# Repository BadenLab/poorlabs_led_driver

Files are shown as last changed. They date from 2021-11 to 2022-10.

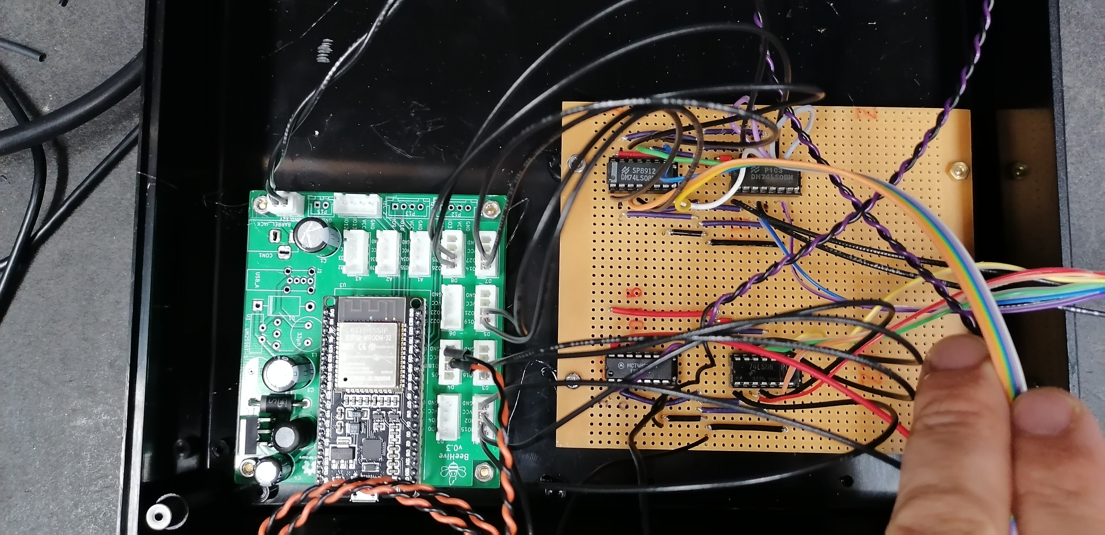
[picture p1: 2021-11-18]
media/IMG_20211118_184615.jpg

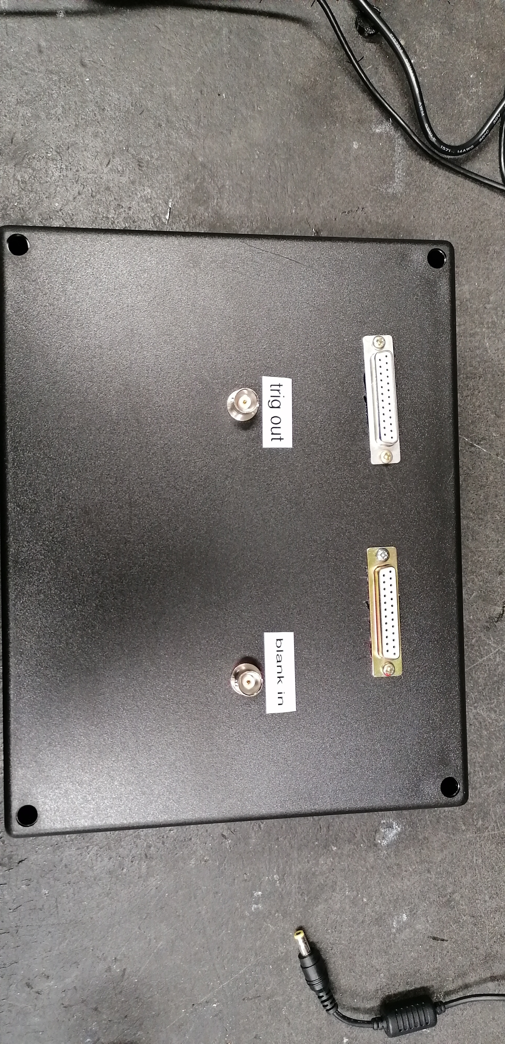
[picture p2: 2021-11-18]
media/IMG_20211118_184739.jpg

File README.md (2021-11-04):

# Poorlabs stimulus generator
A custom driver for Chrolis LED system from ThorLabs

This repository contains all the documentation needed to build a custom driver for a [Chrolis LED system from Thorlabs](https://www.thorlabs.com/newgrouppage9.cfm?objectgroup_id=13597).

Features:
- Synchronisation with 2 photon microscope blanking signal (or any other synchronisation TTL pulse)
  - Synchronisation done via hardware, dispensing the need to include complicated logic on the microcontroller
- Based on ESP32 (uses [BeeHive](https://github.com/BeeHive-org/BeeHive) main breakout board)
- Set of stimuli provided. Based on [Led Zappelin's code](https://github.com/BadenLab/LED-Zappelin)

Skills required:
- Coding (Arduino IDE / Micropython)
- Soldering
- Using a drill, screwdriver

Links/tutorials used:
- [getting started with ESP 32 and micropython](https://docs.micropython.org/en/latest/esp32/tutorial/intro.html)
- [controlling an ESP with micropython via a Jupyter notebook](https://towardsdatascience.com/micropython-on-esp-using-jupyter-6f366ff5ed9) 
- datasheets:
  - [Chips performing logical AND on the signals to control each LED and the blanking signal](https://www.mouser.co.uk/datasheet/2/308/74LS08-1190273.pdf)
  - [Chip inverting the blanking signal (logical NOT)](https://www.mouser.co.uk/datasheet/2/308/1/MC74HC14A_D-2315678.pdf)

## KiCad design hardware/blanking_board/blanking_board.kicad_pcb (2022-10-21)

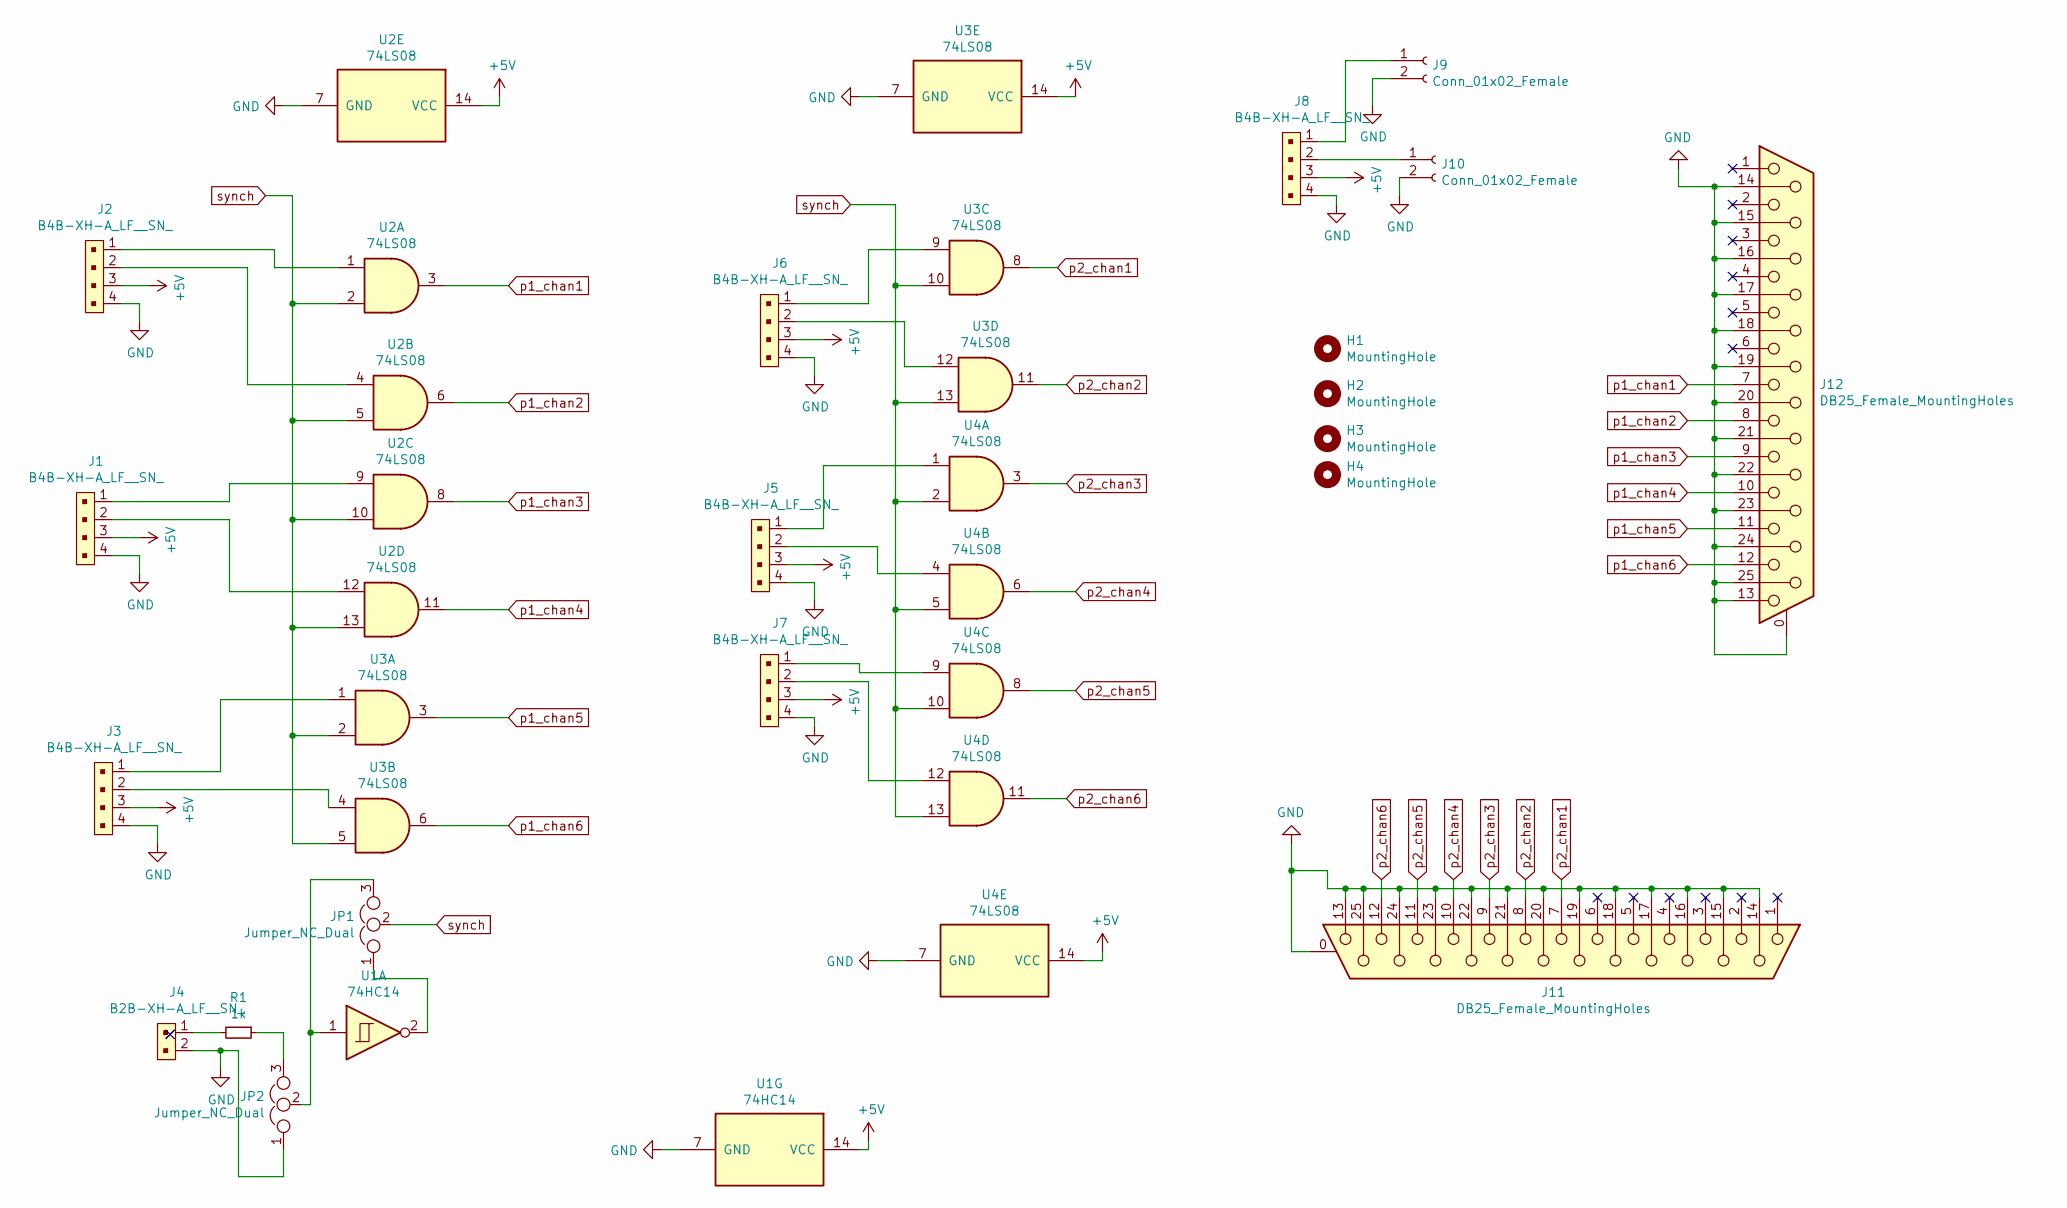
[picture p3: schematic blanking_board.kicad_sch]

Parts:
H1, H2, H3, H4: MountingHole; MountingHole_3.2mm_M3_ISO7380
J1, J2, J3, J5, J6, J7, J8: B4B-XH-A_LF__SN_; JST_XH_B4B-XH-A_1x04_P2.50mm_Vertical; MPN B4B-XH-A(LF)(SN); Digi-Key_PN 455-2249-ND
J4: B2B-XH-A_LF__SN_; JST_XH_B2B-XH-A_1x02_P2.50mm_Vertical; MPN B2B-XH-A(LF)(SN); Digi-Key_PN 455-2247-ND
J9, J10: Conn_01x02_Female; JST_XH_B2B-XH-A_1x02_P2.50mm_Vertical
J11, J12: DB25_Female_MountingHoles; PinHeader_2x13_P2.54mm_Vertical
JP1, JP2: Jumper_NC_Dual; PinHeader_1x03_P2.54mm_Vertical
R1: 1k; R_Axial_DIN0411_L9.9mm_D3.6mm_P15.24mm_Horizontal
U1: 74HC14; DIP-14_W7.62mm_LongPads
U2, U3, U4: 74LS08; DIP-14_W7.62mm_LongPads

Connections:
+5V: J1.3, J2.3, J3.3, J5.3, J6.3, J7.3, J8.3, U1.14 (VCC), U2.14 (VCC), U3.14 (VCC), U4.14 (VCC)
GND: J1.4, J2.4, J3.4, J4.2, J5.4, J6.4, J7.4, J8.4, J9.2, J10.2, J11.0 (PAD), J11.13, J11.14, J11.15, J11.16, J11.17, J11.18, J11.19, J11.20, J11.21, J11.22, J11.23, J11.24, J11.25, J12.0 (PAD), J12.13, J12.14, J12.15, J12.16, J12.17, J12.18, J12.19, J12.20, J12.21, J12.22, J12.23, J12.24, J12.25, JP2.1, U1.7 (GND), U2.7 (GND), U3.7 (GND), U4.7 (GND)
unnamed: J1.1, U2.9
unnamed: J1.2, U2.12
unnamed: J2.1, U2.1
unnamed: J2.2, U2.4
unnamed: J3.1, U3.1
unnamed: J3.2, U3.4
unnamed: J4.1, R1.2
unnamed: J5.1, U4.1
unnamed: J5.2, U4.4
unnamed: J6.1, U3.9
unnamed: J6.2, U3.12
unnamed: J7.1, U4.9
unnamed: J7.2, U4.12
unnamed: J8.1, J9.1
unnamed: J8.2, J10.1
unnamed: JP1.1, U1.2
unnamed: JP1.3, JP2.2, U1.1
unnamed: JP2.3, R1.1
p1_chan1: J12.7, U2.3
p1_chan2: J12.8, U2.6
p1_chan3: J12.9, U2.8
p1_chan4: J12.10, U2.11
p1_chan5: J12.11, U3.3
p1_chan6: J12.12, U3.6
p2_chan1: J11.7, U3.8
p2_chan2: J11.8, U3.11
p2_chan3: J11.9, U4.3
p2_chan4: J11.10, U4.6
p2_chan5: J11.11, U4.8
p2_chan6: J11.12, U4.11
synch: JP1.2, U2.2, U2.5, U2.10, U2.13, U3.2, U3.5, U3.10, U3.13, U4.2, U4.5, U4.10, U4.13

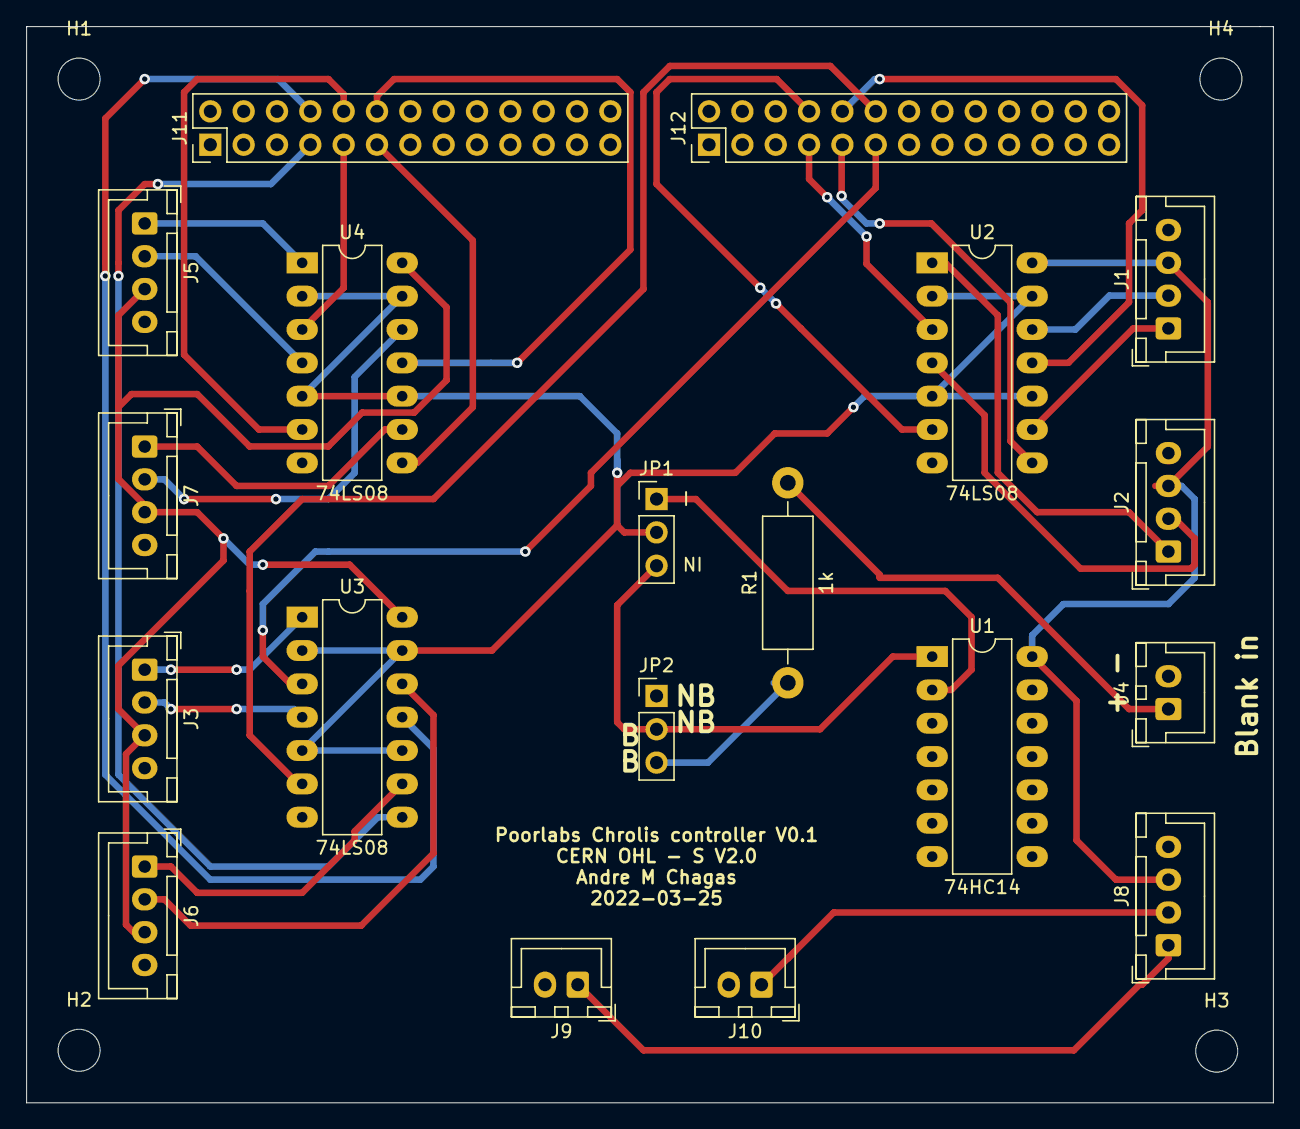
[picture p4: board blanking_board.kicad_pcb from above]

Board: 2 copper layers, 95.0 x 82.0 mm, 23 parts (0 on the bottom side), 33 nets.

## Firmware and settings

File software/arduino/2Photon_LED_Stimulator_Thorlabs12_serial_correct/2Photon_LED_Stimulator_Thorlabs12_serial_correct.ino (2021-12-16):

/*
 * Adapting this code to only ESP32:
 * Change the LEDX values (in the very beginning of the code), to values that correspond to pin numbers on the Beehive 0.3 board
 * change the "tlc.setPWM(ledX,0);" calls to "ledcWrite(ledX, value)"
 * remove or comment out "tlc.write()"
 * 
 * 
 */


/* 
 
        LED Zappelin' is an open hardware LED stimulator that can individually                                                                                                                                                                                                                                                                                                                                      
control up to 24 LEDs.

This Arduino file is designed to be uploaded on an Adafruit_HUZZAH ESP32 Feather or an Arduino Nano
Source : https://github.com/BadenLab/LED-Zappelin
The script relies on an incoming blanking signal, generated by a TTL, which updates the LEDs.
The stimulus speed has to be adjusted to the scan logic (scanning mirrors speed that corresponds to 
the blanking signal generated by the TTL): 1kHz/1ms, 500Hz/2ms, etc.
A trigger signal is generated at the begining of the stimulus and then every 1.0 seconds.

Library "Adafruit TLC5947" needs to be installed.
 
The default script is parametered for 4 LEDs (connected to pin 0 to 3), and their respective proxy LEDs 
(connected to pin 4 to 7)


This project is Open Source licensed, released under CERN OHL v1.2

by  M.J.Y. Zimmermann, 2019.02.05
Baden Lab, CRPC, School of Life Sciences, University of Sussex, United Kingdom
*/


//libraries
#include <SerialCommand.h>


/* ------------------------------------------------------------------------------------
                           Stimulus parameters
-------------------------------------------------------------------------------------*/                                                                                             

int           nLoops           = 500;     //  Number of repeats of the arrays (i.e. Loops)
const int     nArrayEntries    = 3;       //  Number of entries in the arrays, including preadaption at position 0
const int     Scan_Logic       = 2;       //  Scanning logic (1 for 1ms scans, 2 for 2ms scans, etc.)



// // // // // // // // // // // // // // // // // // // // // // // // // // //
// // // // // // // // // STIMULUS SEQUENCE START // // // // // // // // // //
// // // // // // // // // // // // // // // // // // // // // // // // // // // 

// The array_LED# values are expressed in percentage and should only be expressed from 0-100
const int8_t array_LED1[] PROGMEM = {
0,100,0
};
const int8_t array_LED2[] PROGMEM = {    
0,0,0
};
const int8_t array_LED3[] PROGMEM = {    
0,0,0
};
const int8_t array_LED4[] PROGMEM = {
0,0,0
};

const int8_t array_LED5[] PROGMEM = {
0,0,0
};
const int8_t array_LED6[] PROGMEM = {    
0,0,0
};
const int8_t array_LED7[] PROGMEM = {    
0,0,0
};
const int8_t array_LED8[] PROGMEM = {
0,0,0
};
const int8_t array_LED9[] PROGMEM = {
0,0,0
};
const int8_t array_LED10[] PROGMEM = {    
0,0,0
};
const int8_t array_LED11[] PROGMEM = {    
0,0,0
};
const int8_t array_LED12[] PROGMEM = {
0,0,0
};


// The array_Time values are expressed in milliseconds
const int16_t array_Time[] PROGMEM = {      
10,1000,1000
};

// // // // // // // // // // // // // // // // // // // // // // // // // // //
// // // // // // //  STIMULUS SEQUENCE END  // // // // // // // // // // // //
// // // // // // // // // // // // // // // // // // // // // // // // // // //


/* ------------------------------------------------------------------------------------
                           Microcontroller Board Selection
-------------------------------------------------------------------------------------*/

      //#define Arduino_Nano
      //#define Adafruit_ESP32

      
/* ------------------------------------------------------------------------------------
                    Internal Definitions (Change at your own risk)
-------------------------------------------------------------------------------------*/
// setting PWM properties
const int freq = 5000;
const int resolution = 12;

// defining LEDs arduino channels
const int led1Channel = 0;
const int led2Channel = 1;
const int led3Channel = 2;
const int led4Channel = 3;

const int led5Channel = 4;
const int led6Channel = 5;
const int led7Channel = 6;
const int led8Channel = 7;
const int led9Channel = 8;
const int led10Channel = 9;
const int led11Channel = 10;
const int led12Channel = 11;



#include "LED_Values.h"                     // Include LED Values defined in the second tab
/*
#include <SPI.h>                            // Include the arduino serial port interface library
#include "Adafruit_TLC5947.h"               // Include the Adafruit TLC5947 libvrary. For better result one may change the number of channel defined in the Adafruit_TLC5947.cpp library


#ifdef Arduino_Nano
    #define   data            4             // SPI connection, DIN connected to pin D4
    #define   clock           5             // SPI connection, CLK connected to pin D5
    #define   latch           6             // SPI connection, LAT connected to pin D6
    //#define   oe              2           // Optional feature to prevent LED to light up when powering up the TLC board connected to pin D2
    const int      pSyncOut      =   A0;    // Trigger channel must be connected to pin A0
    const int      pBlank        =   3;     // Blanking signal channel must be connected to pin D3
#endif

#ifdef Adafruit_ESP32
    #define   data           18             // SPI connection, DIN connected to pin MOSI/18
    #define   clock           5             // SPI connection, CLK connected to pin SCK/5
    #define   latch          21             // SPI connection, LAT connected to pin 21
    //#define   oe            25            // Optional feature to prevent LED to light up when powering up the TLC board connected to pin A1/DAC1
    const int      pSyncOut      =   26;    // Trigger channel must be connected to pin A0/DAC2
    const int      pBlank        =   36;    // Blanking signal channel must be connected to pin A4/36
#endif

//    Adafruit_TLC5947 tlc = Adafruit_TLC5947(1, clock, data, latch);

*/
    

/* Global variables */  

//char           sCmd;                        // Serial monitor 
SerialCommand sCmd;     // The demo SerialCommand object
int            i;                           // iteration loop factor
word           BaudRate      = 115200;      // Baud Rate
// Label LEDs with GPIO pins
int            led1Pin       = 16;           // Define 1st Channel (Beehive)       
int            led2          = 17;           // Define 2nd Channel
int            led3          = 5;            // Define 3rd Channel
int            led4          = 18;           // Define 4th Channel

int            led5          = 19;           // Define 5th Channel        
int            led6          = 21;           // Define 6th Channel
int            led7          = 22;           // Define 7th Channel 
int            led8          = 23;           // Define 8th Channel 
int            led9          = 14;           // Define 9th Channel (Beehive)
int            led10         = 27;           // Define 10th Channel (Beehive)
int            led11         = 26;          // Define 11th Channel (Beehive)
int            led12         = 25;          // Define 12th Channel (Beehive)


/* Global LED variables */
volatile word   stled1;                     // First LED value   
volatile word   stled2;                     // Second LED value
volatile word   stled3;                     // Third LED value
volatile word   stled4;                     // Fourth LED value

volatile word   stled5;                     // Fifth LED value   
volatile word   stled6;                     // Sixth LED value
volatile word   stled7;                     // Seventh LED value
volatile word   stled8;                     // Eighth LED value
volatile word   stled9;                     // Ninth LED value   
volatile word   stled10;                     // Tenth LED value
volatile word   stled11;                     // Eleventh LED value
volatile word   stled12;                     // Twelfth LED value

word            array1[nArrayEntries];      // First LED Array
word            array2[nArrayEntries];      // Second LED Array
word            array3[nArrayEntries];      // Third LED Array
word            array4[nArrayEntries];      // Fourth LED Array

word            array5[nArrayEntries];      // Fifth LED Array
word            array6[nArrayEntries];      // Sixth LED Array
word            array7[nArrayEntries];      // Seventh LED Array
word            array8[nArrayEntries];      // Eighth LED Array
word            array9[nArrayEntries];      // Ninth LED Array
word            array10[nArrayEntries];      // Tenth LED Array
word            array11[nArrayEntries];      // Eleventh LED Array
word            array12[nArrayEntries];      // Twelfth LED Array


/* Timing variables */
volatile word  pulse;                                             // Pulse number
word           Time[nArrayEntries];                               // Time Array
float          x_Logic            =   1.0/Scan_Logic;             // Factor applied to the timing according to the scanning logic

/* Trigger variables */
int     Trigger_Duration            =   25;                       // Length of the Trigger signal in ms
int     TriggerCounter_Duration     =   1000;                     // Lenght of the Trigger loop in ms
word    Trigger_dur        =   Trigger_Duration * x_Logic;        // Trigger signal duration adjusted
word    TriggerCounter_dur =   TriggerCounter_Duration * x_Logic; // Trigger loop duration adjusted  
    
/* Reset Parameters */
volatile word  iLoop                = 0;       // Actual loop number = iLoop + 1
volatile word  PulseCount           = 0;       // Count the number of pulses delivered by the blanking signal
volatile int   PulseCount_Trigger   = 0;       // Count the number of pulses generated for the trigger channel (A0 pin)
volatile int   ArrayPosition        = 0;       // Position array within the current loop

/* Flags */
bool   SettingFlag   =  true;
bool   BlankingFlag  =  true;


/* -----------------------------------------------------------------------------------
                                 Internal methods
 ------------------------------------------------------------------------------------*/

void setup(){

// Initialise the serial communication with PC
  Serial.begin(BaudRate);

// Initialise the Adafruit TLC driver 
  //tlc.begin();
  //tlc.write();  

// Set pins
  //pinMode(pSyncOut, OUTPUT);  
  //digitalWrite(pSyncOut, LOW);  
  //pinMode(pBlank, INPUT);
  ////digitalWrite(pBlank, HIGH);



// configure LED PWM functionalitites
  ledcSetup(led1Channel, freq, resolution);
  ledcSetup(led2Channel, freq, resolution);
  ledcSetup(led3Channel, freq, resolution);
  ledcSetup(led4Channel, freq, resolution);
  
  ledcSetup(led5Channel, freq, resolution);
  ledcSetup(led6Channel, freq, resolution);
  ledcSetup(led7Channel, freq, resolution);
  ledcSetup(led8Channel, freq, resolution);
  ledcSetup(led9Channel, freq, resolution);
  ledcSetup(led10Channel, freq, resolution);
  ledcSetup(led11Channel, freq, resolution);
  ledcSetup(led12Channel, freq, resolution);
  
  
// attach the channel to the GPIO to be controlled
  ledcAttachPin(led1Pin, led1Channel);
  ledcAttachPin(led2, led2Channel);
  ledcAttachPin(led3, led3Channel);
  ledcAttachPin(led4, led4Channel);
  
  ledcAttachPin(led5, led5Channel);
  ledcAttachPin(led6, led6Channel);
  ledcAttachPin(led7, led7Channel);
  ledcAttachPin(led8, led8Channel);
  ledcAttachPin(led9, led9Channel);
  ledcAttachPin(led10, led10Channel);
  ledcAttachPin(led11, led11Channel);
  ledcAttachPin(led12, led12Channel);
  
  ledcWrite(led1Channel, 0);
  // do for all leds
 // attach functions (after void loop) to callbacks
 sCmd.addCommand("a", a);
 sCmd.addCommand("b", b);
 sCmd.addCommand("off", Play0);
 sCmd.addCommand("playarrays", PlayArrays);
 
}// end setup

/* ----------------------------------------------------------------------------------*/
/* -------------------------------- Turn all LED off --------------------------------*/






/* ----------------------------------------------------------------------------------*/
/* ----------------------------------- Main Loop ------------------------------------*/

void loop(){

// Check if command received from PC
  //if(Serial.available()) {
    //sCmd = Serial.read();
    sCmd.readSerial();     // We don't do much, just process serial commands
}// end void loop
// Execute command
    //switch (sCmd) {


void Play0(){
      ledcWrite(led1Pin, 0);                            // Set First LED to 0
      ledcWrite(led2,0);                                // Set Second LED to 0
      ledcWrite(led3,0);                                // Set Third LED to 0 
      ledcWrite(led4,0);                                // Set Fourth LED to 0
      
      ledcWrite(led5,0);                                // Set Fifth proxy LED to 0
      ledcWrite(led6,0);                                // Set Sixth proxy LED to 0
      ledcWrite(led7,0);                                // Set Seventh proxy LED to 0 
      ledcWrite(led8,0);                                // Set Eighth proxy LED to 0
      ledcWrite(led9, 0);                               // Set Ninth LED to 0
      ledcWrite(led10,0);                               // Set Tenth LED to 0
      ledcWrite(led11,0);                               // Set Eleventh LED to 0 
      ledcWrite(led12,0);                               // Set Twelfth LED to 0
      
      //tlc.write();   
      Serial.println("-> All LEDs off"); 
      
//probably don't need these counters can just use inbuilt timer      
      PulseCount = 0;                                    // Reset Pulse counter
      PulseCount_Trigger = 0;                            // Reset Trigger pulse counter
      ArrayPosition = 0;                                 // Reset Array counter
      
      SettingFlag = true;                                // Return to initial condition
      BlankingFlag = true;                               // Return to initial condition
}


/* ----------------------------------------------------------------------------------*/
/* ------------------------------ Play Stimulus Array -------------------------------*/

void PlayArrays() {

/* Defining timing according to the current array position */
    pulse = Time[ArrayPosition];
    
/* Trigger ------------------------------------------------------------------------*/

    /* Keep Trigger on for the trigger duration */
    if(PulseCount_Trigger <= Trigger_dur && ArrayPosition > 0){
        PulseCount_Trigger += 1;                         // Trigger Pulse Counter, move to the next pulse
    } 
    /* Keep Trigger off for the rest of the trigger duration */
    if(PulseCount_Trigger > Trigger_dur && ArrayPosition > 0){
        //digitalWrite(pSyncOut, LOW);                     // Turn Trigger off
        PulseCount_Trigger += 1;                         // Trigger Pulse Counter, move to the next pulse
    }

    /* Once Trigger duration is reached, reset counter and turn trigger on */
    if(PulseCount_Trigger == TriggerCounter_dur+1 && ArrayPosition > 0){
        PulseCount_Trigger = 0;                          // Reset Trigger pulse counter
        //digitalWrite(pSyncOut, HIGH);                    // Turn Trigger on
    }
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

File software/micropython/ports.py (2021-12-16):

#import necessary libraries on the esp32
import machine

# The ESP model being used only has 8 native PWM ports.
# to circunvent this, we are using a library (below), that makes use
# of the built remote control module native to the ESP32. 
# this gives us another 8 PWM ports.

# library location https://github.com/codemee/esp32_rmt_pwm
from esp32_rmt_pwm import PWM


class Leds:
    def __init__(self):
        #port 1 on the controller box
        led1Pin = 19
        led2Pin = 21
        led3Pin = 14
        led4Pin = 27
        led5Pin = 26
        led6Pin = 25

        #port 2 on the controller box
        led7Pin = 15
        led8Pin = 2
        led9Pin = 16
        led10Pin = 17
        led11Pin = 22
        led12Pin = 23


        triggerPin = 18 
        self.trigger = machine.Pin(triggerPin, machine.Pin.OUT)

        #the refresh rate frequency of the PWM signals
        pwmFreq = 1000
        #resolution of the pwm in bits (will lead to a number of light intensity steps)
        #self.resolution = 10

        #note: the lines below could be done in a loop, but would become more criptic
        #check https://docs.micropython.org/en/latest/esp32/tutorial/pwm.html#esp32-pwm
        # for details

        #all led pins are set to PWM so we can control the LED intensity
        
        self.led1 = machine.PWM(machine.Pin(led1Pin))
        self.led2 = machine.PWM(machine.Pin(led2Pin))
        self.led3 = machine.PWM(machine.Pin(led3Pin))
        self.led4 = machine.PWM(machine.Pin(led4Pin))
        self.led5 = machine.PWM(machine.Pin(led5Pin))
        self.led6 = machine.PWM(machine.Pin(led6Pin))

    
        self.led7 = PWM(machine.Pin(led7Pin)) 
        self.led8 = PWM(machine.Pin(led8Pin))
        self.led9 = PWM(machine.Pin(led9Pin))
        self.led10 = PWM(machine.Pin(led10Pin))
        self.led11 = PWM(machine.Pin(led11Pin))
        self.led12 = PWM(machine.Pin(led12Pin))
        
        
        #make a list with all leds so that it is easier to control all of them with loops
        self.allLedsP1 = [self.led1,self.led2,self.led3,self.led4,self.led5,self.led6]
        self.allLedsP2 = [self.led7,self.led8,self.led9,self.led10,self.led11,self.led12]
                        

        #turn all leds off for good measure
        for led in self.allLedsP1:
            led.init(freq=pwmFreq, duty=0)
        
        for led in self.allLedsP2:
            led.init(freq=pwmFreq, duty=0)
    
    def deinit(led):
        led.deinit()

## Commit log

2021-11-18 organise repo and work on electronics schematic
    [blanking_board.kicad_pcb, blanking_board.sch]
2021-11-18 schematic update
    [blanking_board.sch]
2021-12-06 Create rig_tester.ino
    bit of code to cycle through leds and sync out signal
2021-12-13 implemented PWM with RMT system and added first example
2022-03-24 update board
    [blanking_board.sch]
2022-03-25 first version of PCB
    [blanking_board-B_Adhes.gbr, blanking_board-B_CrtYd.gbr, blanking_board-B_Cu.gbr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]
2022-07-26 update pcb with jumper for no blanking
    [blanking_board-B_Adhesive.gbr, blanking_board-B_Courtyard.gbr, blanking_board-B_Cu.gbr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]
2022-07-30 more details on board
    [blanking_board-B_Adhesive.gbr, blanking_board-B_Courtyard.gbr, blanking_board-B_Cu.gbr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]
2022-07-30 update training board design
2022-10-21 update board details
    [blanking_board.kicad_pcb, blanking_board.kicad_sch]

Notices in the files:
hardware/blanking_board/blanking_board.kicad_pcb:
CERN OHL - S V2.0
